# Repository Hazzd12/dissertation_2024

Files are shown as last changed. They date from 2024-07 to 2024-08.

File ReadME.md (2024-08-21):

### README.md for Lumiverse Strip

#### Project Overview

The "Lumiverse Strip" is an advanced smart lighting system that utilizes WS2812B LED strips to create a dynamic and responsive environment within smart homes. This system integrates various functionalities such as voice control, music ambience lighting, environmental monitoring, motion detection, gesture and app-controlled text display, weather simulation, and circadian rhythm lighting. The purpose of this project is to demonstrate how smart lighting can enhance user interaction, adapt to environmental changes, and improve the overall quality of life in residential spaces.

#### Features

- **Voice Control**: Manage lighting settings via voice commands.
- **Music Ambience Lighting**: Sync lights with music for immersive experiences.
- **Environmental Monitoring**: Sensors that report real-time data such as temperature, humidity, and air quality.
- **Motion Detection**: Automated lighting adjustments based on detected movement.
- **Gesture and App-Controlled Text Display**: Display messages or alerts through gesture recognition or mobile app interactions.
- **Weather Simulation**: Simulate real-time weather conditions through lighting effects.
- **Circadian Rhythm Lighting**: Adjust lighting to align with natural circadian rhythms to support better sleep patterns and general well-being.

#### Modes

**Moving Mode**

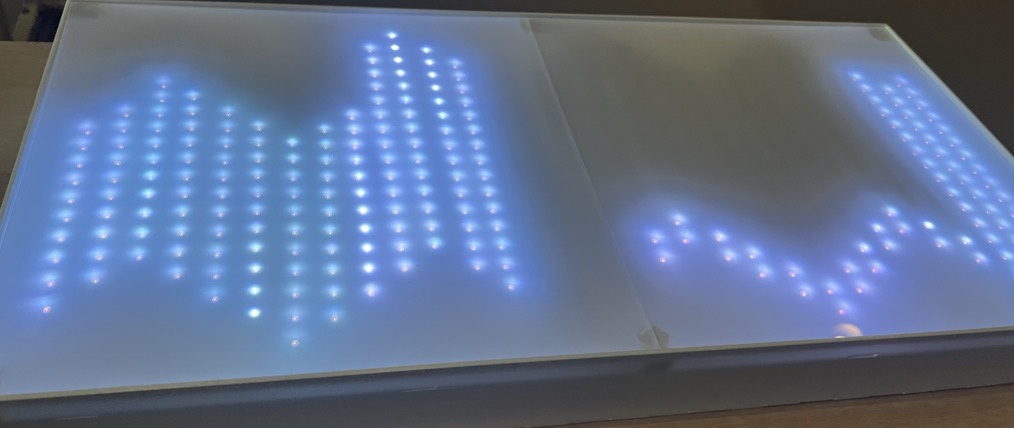
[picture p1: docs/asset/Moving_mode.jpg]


**Music Mode**

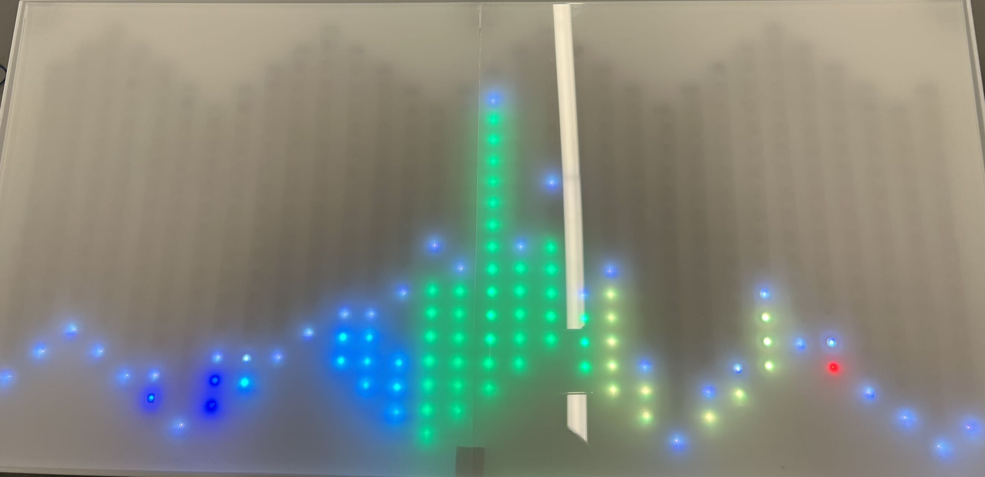
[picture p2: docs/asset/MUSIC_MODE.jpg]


**Environment Mode**

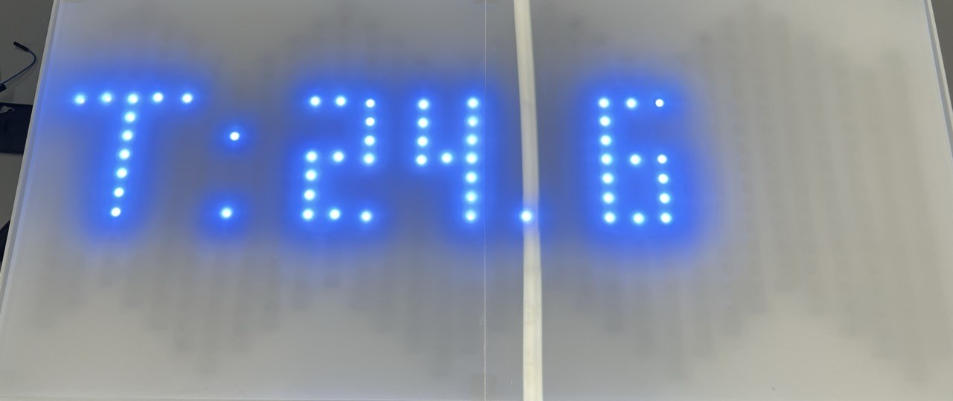
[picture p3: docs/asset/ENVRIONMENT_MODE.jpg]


**Life Mode**

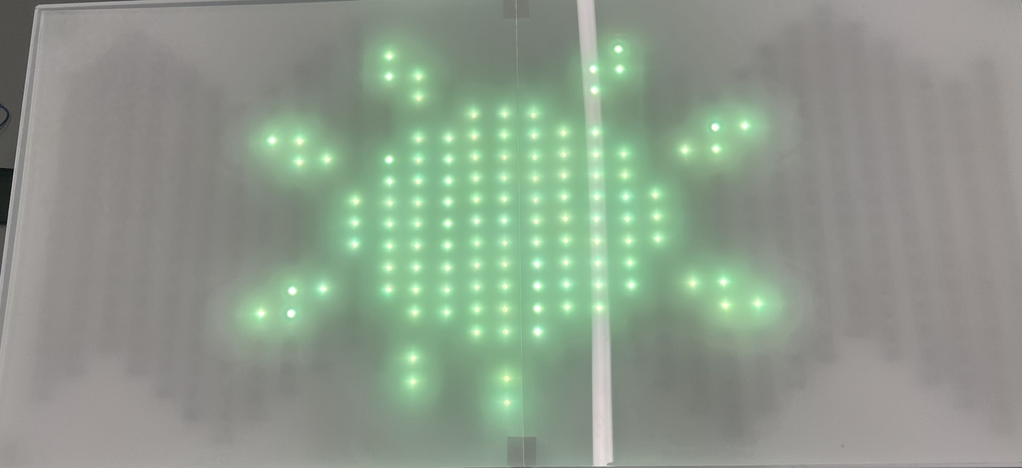
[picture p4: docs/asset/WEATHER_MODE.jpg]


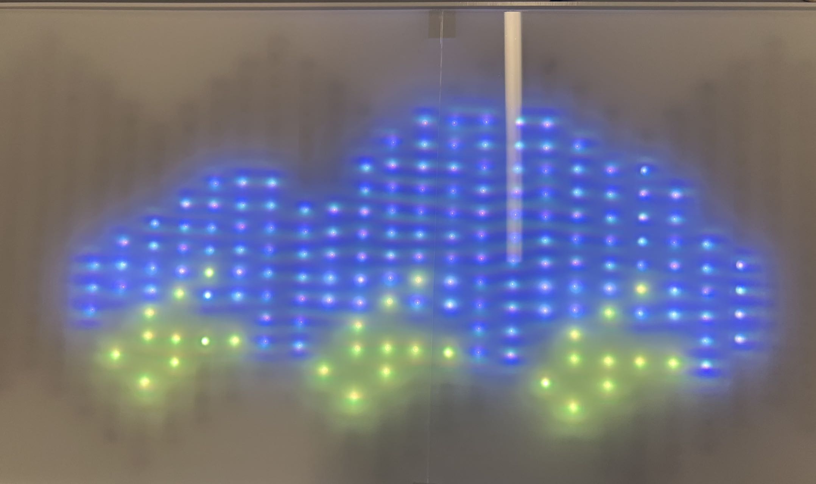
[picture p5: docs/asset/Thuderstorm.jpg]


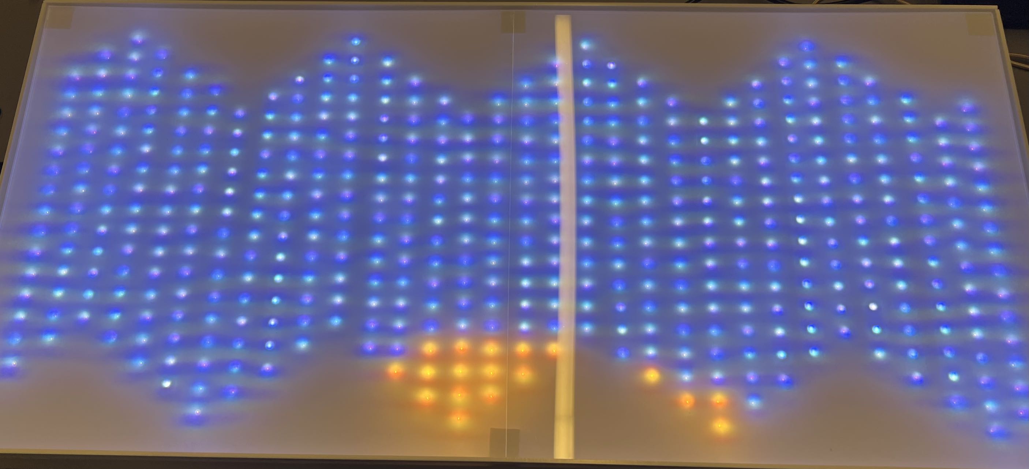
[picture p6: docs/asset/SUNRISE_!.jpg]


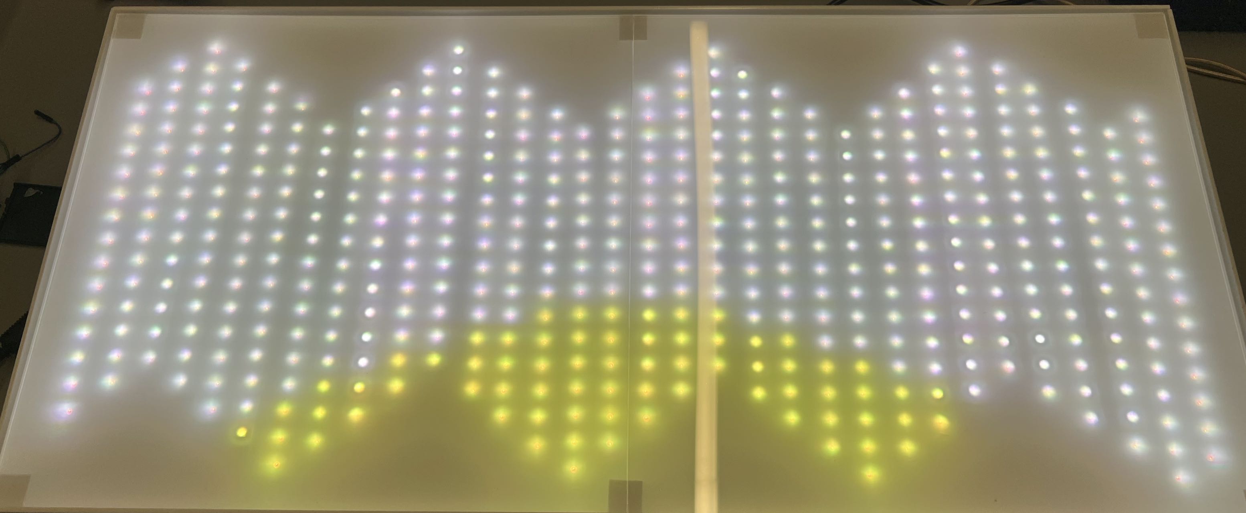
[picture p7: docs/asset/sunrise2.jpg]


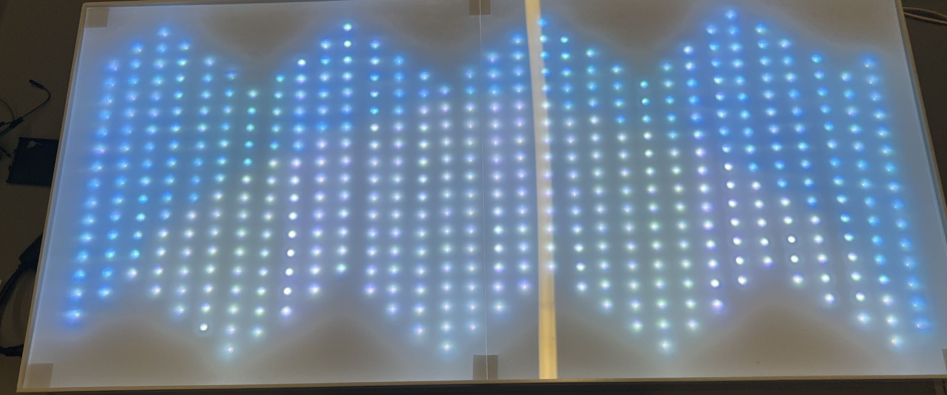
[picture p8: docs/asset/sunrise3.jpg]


****

## How to Make It

### Hardware

* WS2812B LED Strip
* ESP32 Microcontroller
* HC-SR501 PIR Motion Sensors
* MAX9814 Audio Amplifier
* DF2301QG Voice Recognition Module
* BME680 Environmental Sensor
* APDS-9960 Gesture Recognition Sensor
* Power Supply (5V 15A recommended)
* Acrylic sheets (for enclosures)
* Wires, resistors, and other standard electronics components

####  Cut the Enclosures 

* Use a laser cutter to cut 3mm acrylic sheets according to the stored file (path: `./dxf/file_name.dxf`). The names of files represent which part they are belong to.
  * Sensor Box:
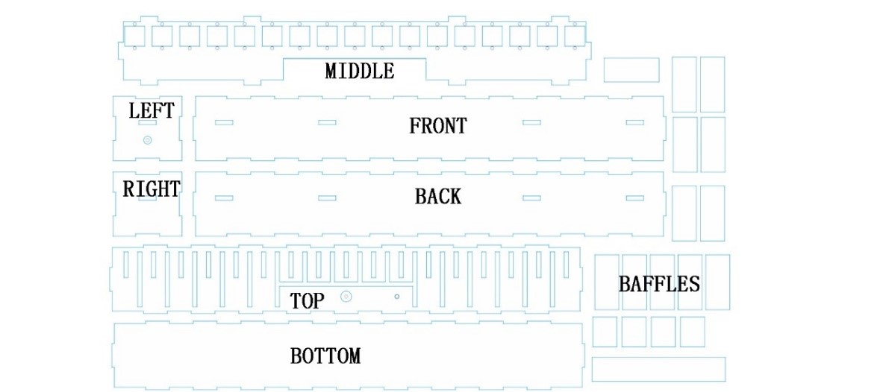
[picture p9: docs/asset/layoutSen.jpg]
    * 
  * Led Box:
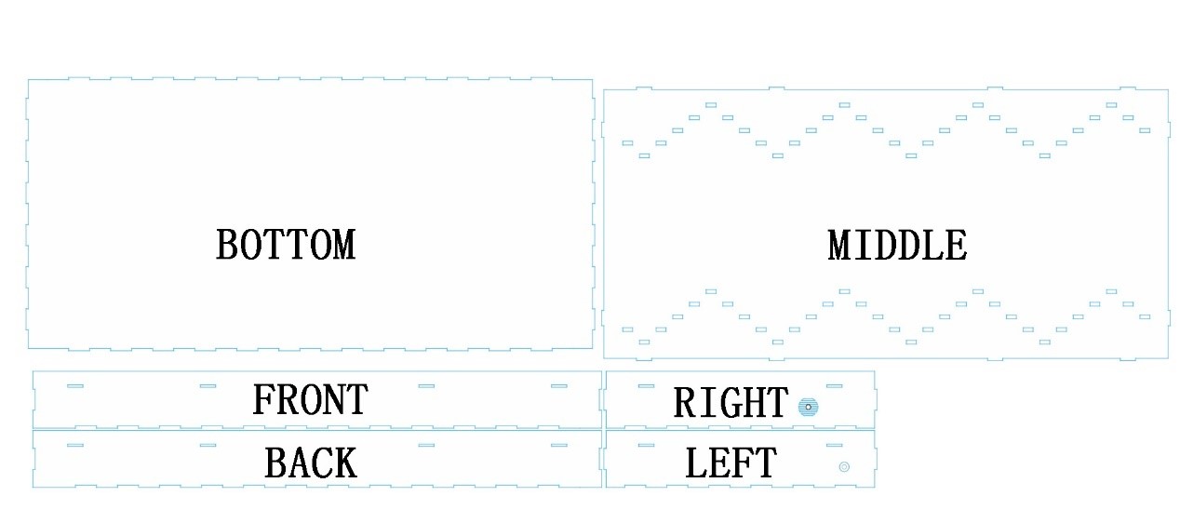
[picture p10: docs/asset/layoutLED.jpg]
    * 

### Assemble the Hardware

1. **Sensor Box Assembly:**

   * Assemble the circuit according to the circuit diagram
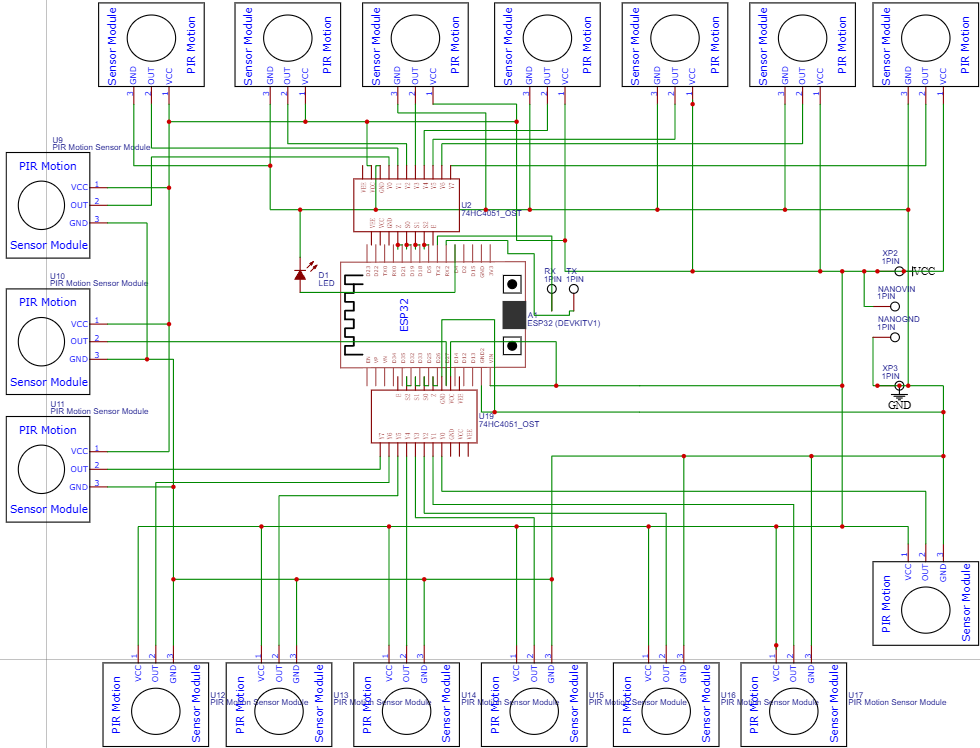
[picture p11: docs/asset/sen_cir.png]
     * 
     * Arrange the WS2812B LED strips in a wavy pattern, aligning with the height differences between the columns.
     * Route the wires (VCC, GND, and data) through the holes in the "MIDDLE" panel and secure them between the "MIDDLE" and "BOTTOM" layers.

   - Insert the PIR sensors into the designated holes in the "MIDDLE" panel.
   - Place the APDS-9960 sensor and the BME680 sensor into their respective slots.
   - Assemble the panels according to the labels, ensuring the correct orientation of each component.

2. **LED Box Assembly:**

   * Assemble the circuit according to the circuit diagram

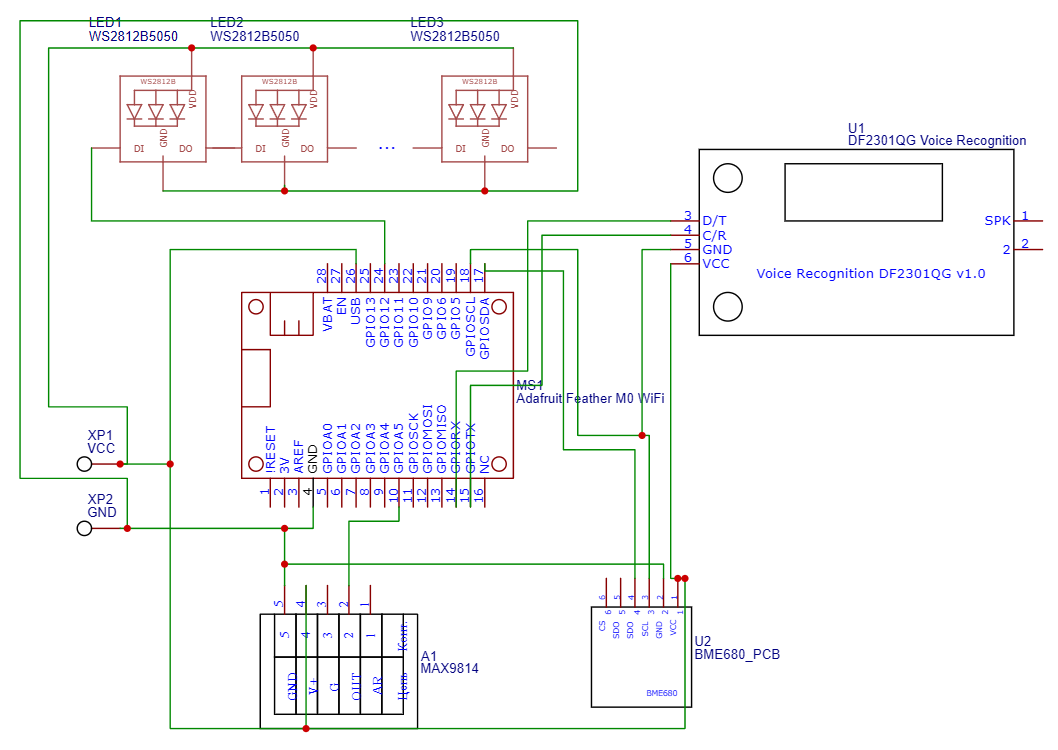
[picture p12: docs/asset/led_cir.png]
     * 

     * Connect the WS2812B LED strips to the microcontroller (Adafruit Feather M0) and ensure the power supply is sufficient to drive the entire strip.

       Connect the BME680 and DF2301QG modules to the microcontroller using I2C and UART, respectively.

   - Arrange the WS2812B LED strips in a wavy pattern, aligning with the height differences between the columns.
   - Route the wires (VCC, GND, and data) through the holes in the "MIDDLE" panel and secure them between the "MIDDLE" and "BOTTOM" layers.
   - Attach the "TOP" panel made of semi-transparent acrylic.

****

 ## Program the Microcontrollers 

**1. Setup Development Environment:**

- Install the necessary libraries for ESP32 and Adafruit Feather M0 on your development environment (e.g., Arduino IDE).
- Clone the repository and upload the provided code(path: `./Arduino/...`) to the respective microcontrollers.
  - `led` folder is provided to Adafruit Feather M0 WiFi (LED Box)
  - `Moving` folder is provided to ESP32 (Sensor Box)
  - `nano` folder is provided to Arduino nano 33 BLE (if you don't have a single APDS-9600, you can use this one)

**2. Configure MQTT:**

- Set up an MQTT broker (e.g., Mosquitto) and configure the microcontrollers to communicate via MQTT for sensor data transmission and LED control.

**3. Test Functionality:**

- Power on the system and verify that each function (e.g., motion detection, voice control, music synchronization) operates as expected.
- Troubleshoot any issues, such as incorrect sensor readings or LED behavior.

****

### Deploy and Enjoy

1. **Deploy the System:**
   - Place the Sensor Box and LED Box in their designated locations within your smart home environment.
   - Ensure they are connected to your home network and the MQTT broker is running smoothly.
2. **Customize and Expand:**
   - Customize the settings via the provided app or adjust the code to better suit your environment.
   - Consider expanding the system with additional sensors or integrating it with other smart home devices.

****

## Flowchart

Here are some flowcharts of the design of the code:

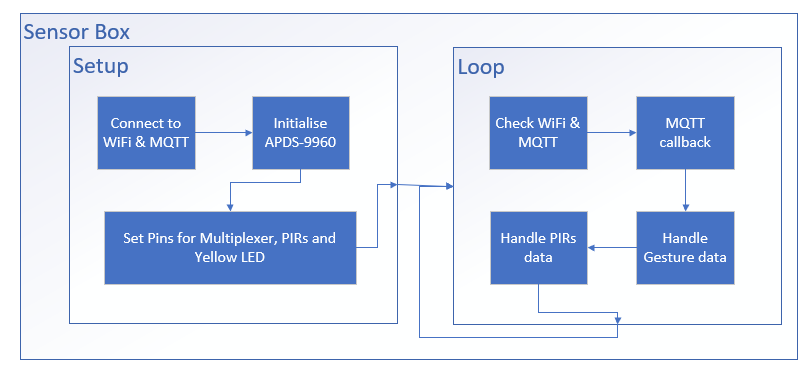
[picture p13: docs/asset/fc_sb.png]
* 
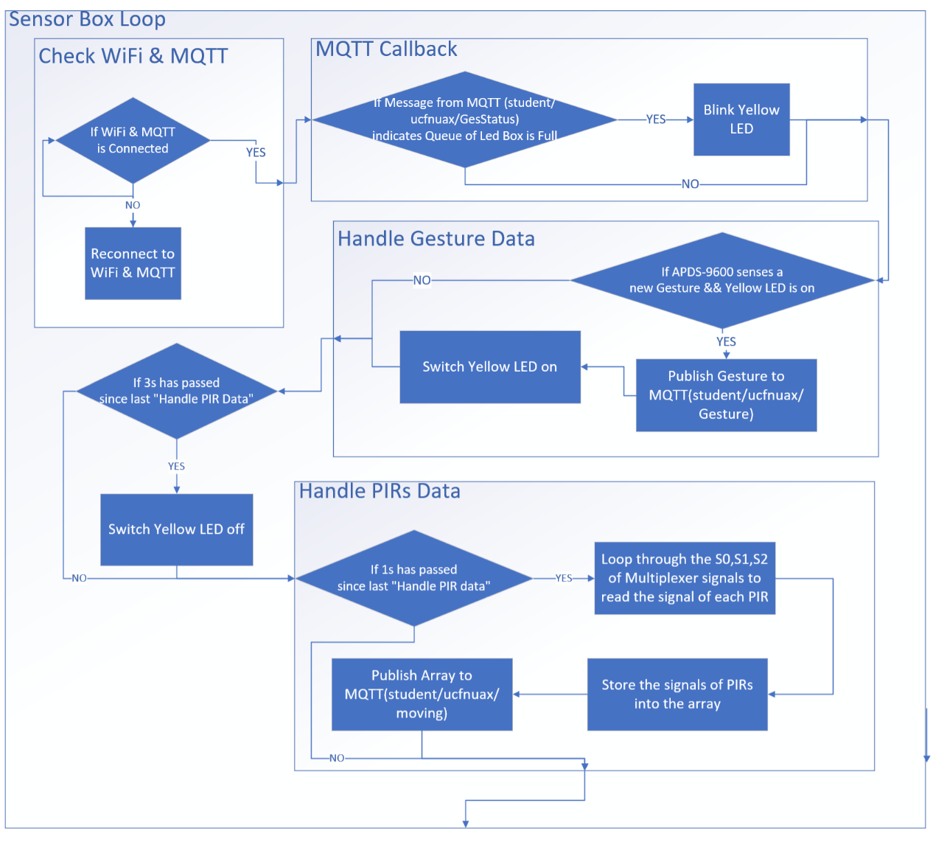
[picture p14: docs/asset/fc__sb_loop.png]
* 
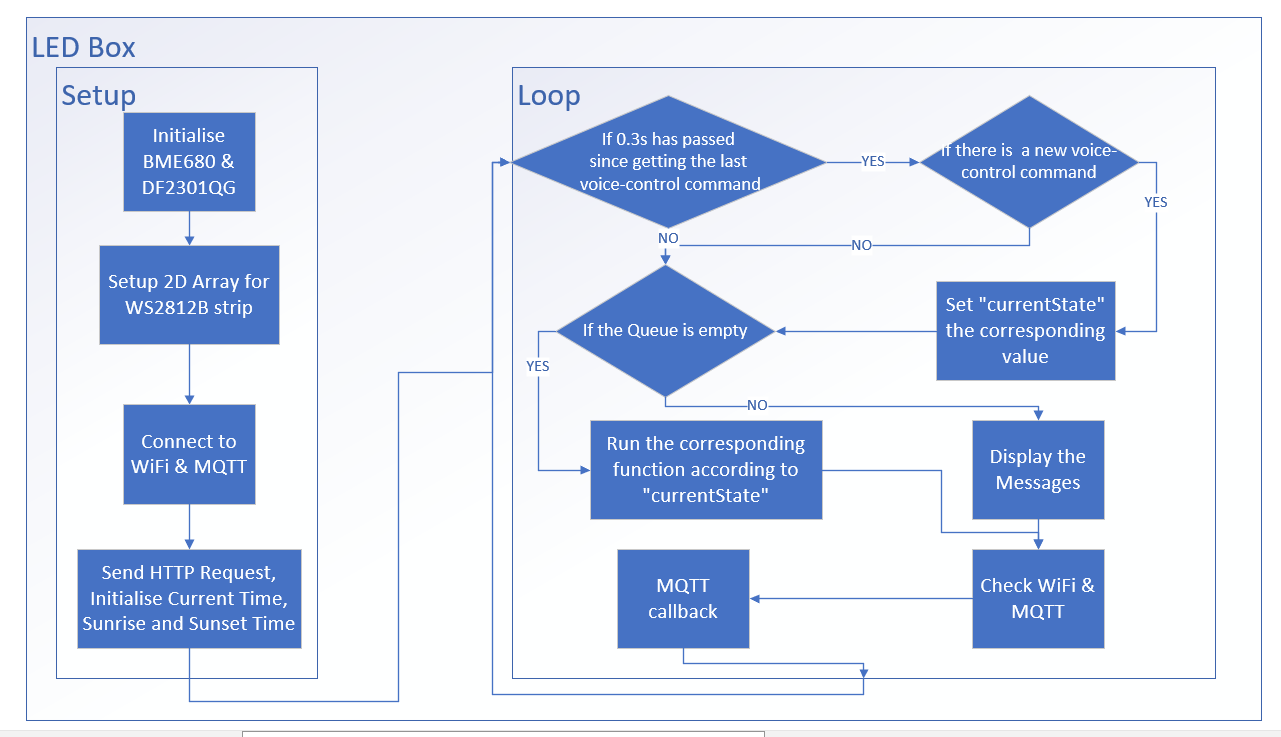
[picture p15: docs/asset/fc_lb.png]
* 
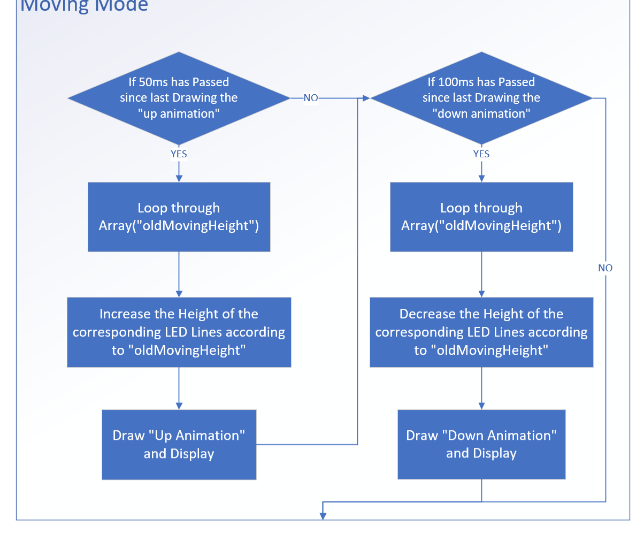
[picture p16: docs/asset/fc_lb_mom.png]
* 
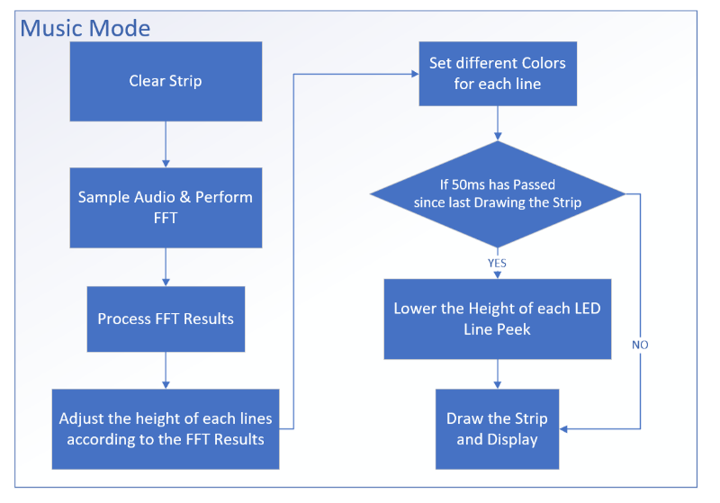
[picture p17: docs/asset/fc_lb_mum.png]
* 
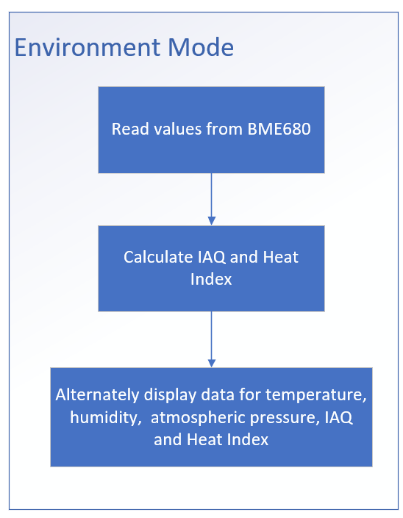
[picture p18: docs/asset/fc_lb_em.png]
* 
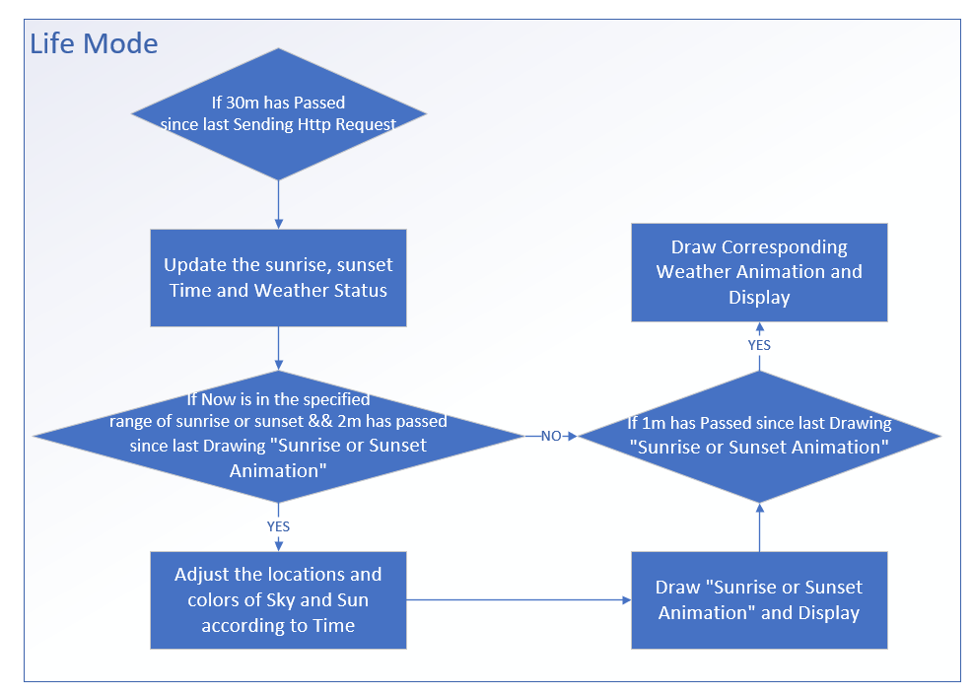
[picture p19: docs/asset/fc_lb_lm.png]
* 

****

## APP

Download apk [here](https://github.com/Hazzd12/dissertation_2024/releases/tag/v1.2.43)

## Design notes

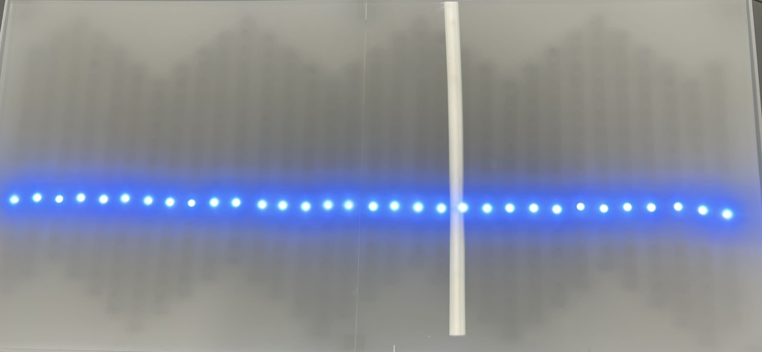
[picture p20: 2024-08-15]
docs/asset/WAKE_MODE.jpg

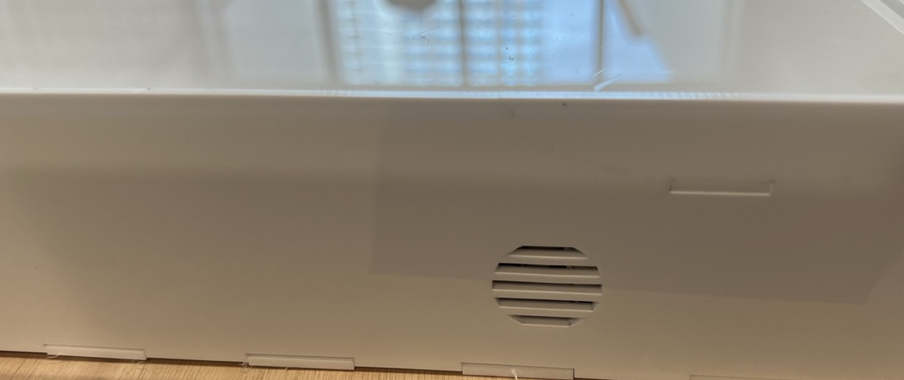
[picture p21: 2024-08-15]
docs/asset/HOLE.jpg

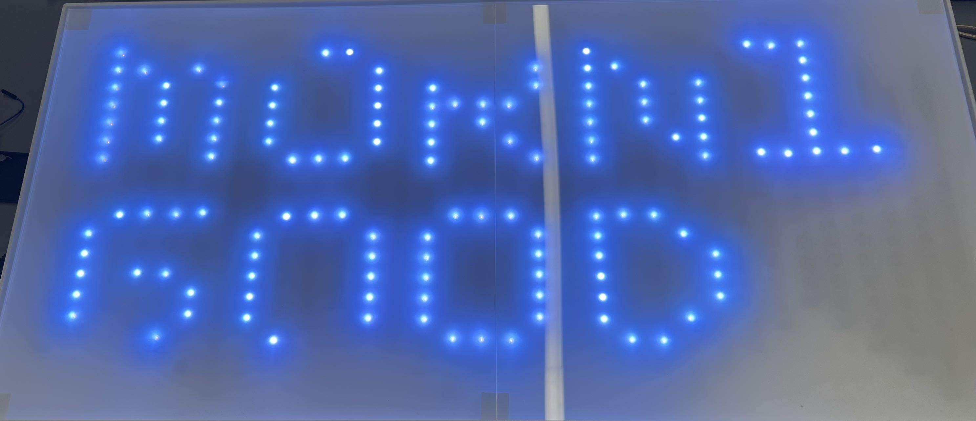
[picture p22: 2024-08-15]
docs/asset/TEXT.jpg

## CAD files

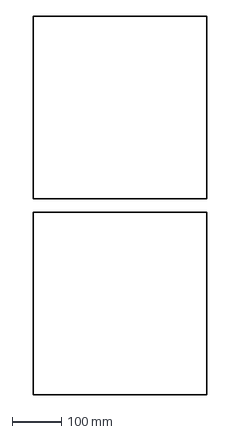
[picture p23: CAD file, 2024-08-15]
dxf/sensor_box_lid.dxf
354.0 x 772.0 mm

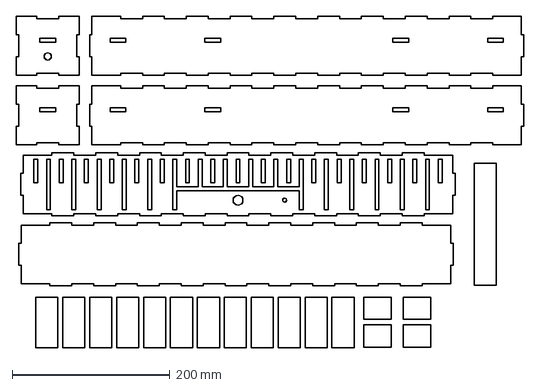
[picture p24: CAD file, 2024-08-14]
dxf/SENSOR_BOX_8.7NEW.dxf
643.0 x 420.0 mm

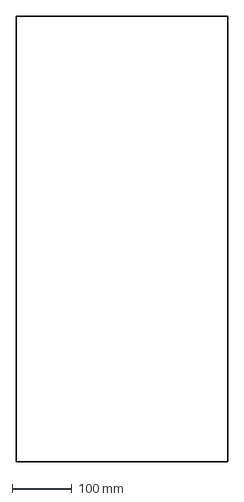
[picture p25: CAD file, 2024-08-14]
dxf/led_box_lid.dxf
354.0 x 744.0 mm

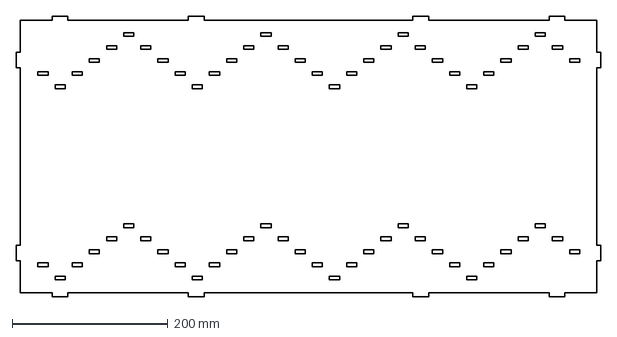
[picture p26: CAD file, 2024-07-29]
dxf/led_middle_5mm.dxf
750.0 x 360.0 mm

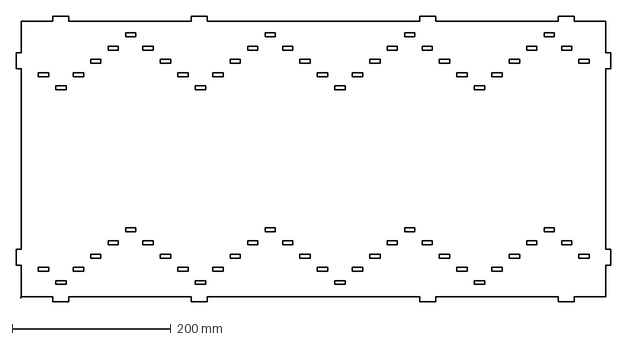
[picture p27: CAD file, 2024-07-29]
dxf/led_middle_6mm.dxf
750.0 x 360.0 mm

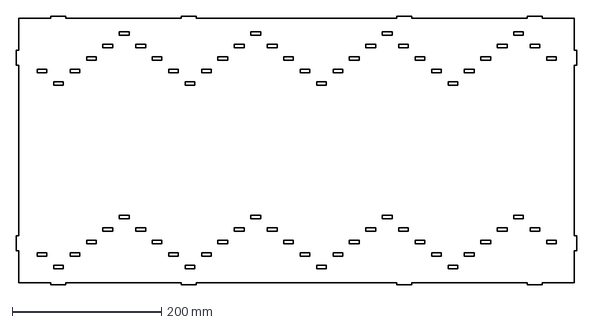
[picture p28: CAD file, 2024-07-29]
dxf/led_middle_3mm.dxf
750.0 x 360.0 mm

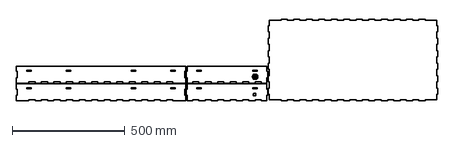
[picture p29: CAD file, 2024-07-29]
dxf/led_box_5mm.dxf
1866.0 x 360.0 mm

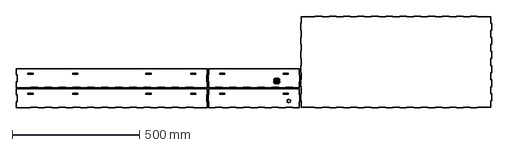
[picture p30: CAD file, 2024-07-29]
dxf/led_box_3mm.dxf
1866.0 x 360.0 mm

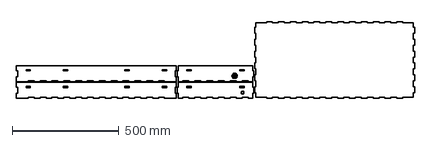
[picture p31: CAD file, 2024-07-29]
dxf/led_box_6mm(new).dxf
1866.0 x 360.0 mm

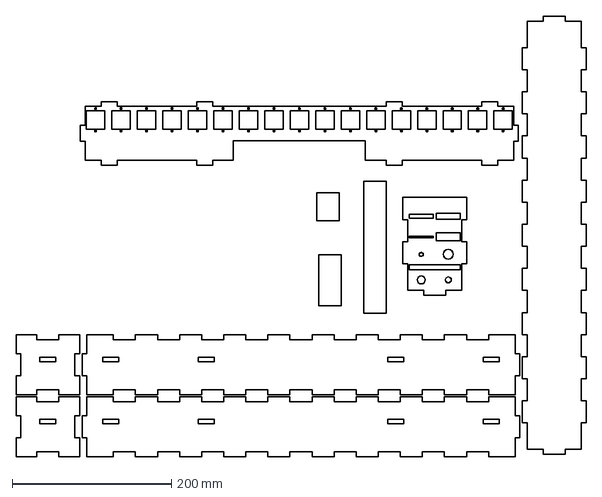
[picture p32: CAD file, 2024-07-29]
dxf/sensor_box_v2.dxf
716.0 x 553.0 mm

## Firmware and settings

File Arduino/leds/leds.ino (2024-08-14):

#include <cppQueue.h>
#include <ArduinoJson.h>
#include "strip.h"
#include "myWifi.h"
#include "MQTTClient.h"
#include "myMusic.h"
#include "LifeAndEnvrionment.h"
#include <Wire.h>
#include <SPI.h>
#include <Adafruit_Sensor.h>
#include "Adafruit_BME680.h"
#include "common.h"
#include "DFRobot_DF2301Q.h"

#define Led 9

DFRobot_DF2301Q_UART* asr;


#define SEALEVELPRESSURE_HPA (1013.25)

Adafruit_BME680 bme;  // I2C

enum State {
  TEST_MODE,
  MOVING_MODE,
  MUSIC_MODE,
  ENVIRONMENT_MODE,
  LIFE_MODE,
  WAKE_MODE
};

State currentState = MOVING_MODE;
State lastState = MOVING_MODE;
int movingArray[17] = { 0 };
int oldMovingHeight[32] = { 0 };

cppQueue myQueue(sizeof(Mes*), 11, FIFO, true);
unsigned long previousMillis = 0;
const long interval = 2000;  // 2 seconds
String segments[10];
int spaces[10];

float temperature = 0;
float humidity = 0;
float pressure = 0;
float gas = 0;
float IAQ = 0;
float heatIndex = 0;

unsigned long lastStringTime = 0;
unsigned long VoiceTime = 0;
unsigned long EnvTime = 0;
int envIndex = 0;
int envDuration = 5000;

int lastTimeCheck = 0;
int lastUpdateTime = 0;
bool ifRiseSet = false;
bool ifWake = false;
bool ifCancelWake = false;

unsigned long lastWake = 0;
void setup() {
  // 初始化灯带
  Serial.begin(9600);
  Serial.println("start");
  delay(1000);

  //BME setup
  Serial.println(F("BME680 test"));

  // Initialize the sensor
  if (!bme.begin()) {
    Serial.println(F("Could not find a valid BME680 sensor, check wiring!"));
  }

  // Set up oversampling and filter initialization
  bme.setTemperatureOversampling(BME680_OS_8X);
  bme.setHumidityOversampling(BME680_OS_2X);
  bme.setPressureOversampling(BME680_OS_4X);
  bme.setIIRFilterSize(BME680_FILTER_SIZE_3);
  bme.setGasHeater(320, 150);  // 320*C for 150 ms

  delay(2000);

  //strip setup
  setupStrip();

  //matrix setup
  ledSetup();
  // initMatrix();
  strip.begin();

  char st1[] = "AUDIO";
  drawString(st1, strip.Color(255, 255, 255), 1, 7);
  strip.show();  // 初始化所有像素为'关'

  asr = new DFRobot_DF2301Q_UART(&Serial1);

  // Init the sensor
  while (!(asr->begin())) {
    Serial.println("Communication with device failed, please check connection");
    delay(3000);
  }
  Serial.println("Begin ok!");

  asr->settingCMD(DF2301Q_UART_MSG_CMD_SET_MUTE, 1);
  asr->settingCMD(DF2301Q_UART_MSG_CMD_SET_VOLUME, 7);
  asr->settingCMD(DF2301Q_UART_MSG_CMD_SET_WAKE_TIME, 10);
  //asr->settingCMD(DF2301Q_UART_MSG_CMD_SET_ENTERWAKEUP, 0);

  asr->playByCMDID(23);
  Serial.println("IN");
  strip.clear();

  char st2[] = "SETUP";
  drawString(st2, strip.Color(255, 255, 255), 1, 7);
  strip.show();  // 初始化所有像素为'关'
  WiFiAndMQTTConnection(callback);


  httpclient.setTimeout(5000);
  // Setup MQTT subscription
  sendGetRequest();
  strip.clear();


  randomSeed(analogRead(2));
}



void loop() {
  MQTTloop();

  unsigned long nowT = millis();
  if (nowT - VoiceTime >= 300) {
    VoiceTime = nowT;
    uint8_t CMDID = asr->getCMDID();

    if (CMDID != 0) {
      Serial.print("CMDID = ");  //打印命令ID
      Serial.println(CMDID);
    }

    switch (CMDID) {
      case 5:  //music

        currentState = MUSIC_MODE;
        break;

      case 6:  //moving
        currentState = MOVING_MODE;
        break;

      case 7:  //life - indoor
        currentState = LIFE_MODE;
        break;

      case 8:  //environment - outdoor
        currentState = ENVIRONMENT_MODE;
        break;

      case 117:
        currentState = TEST_MODE;
        break;
      case 1:
        lastState = currentState;
        currentState = WAKE_MODE;
        ifWake = true;
        lastWake = nowT;
        break;
      default:
        break;
    }
  }

  int queueCount = myQueue.getCount();
  if (queueCount > 0) {
    if (nowT - lastStringTime > 700) {
      drawStrings();
      lastStringTime = nowT;
    }
  } else {
    switch (currentState) {
      case WAKE_MODE:
        if (ifWake) {
          ifWake = false;
          drawHorizontalLine(7);
        }

        if (nowT - lastWake > 5000 ) {
          currentState = lastState;
          strip.clear();
          strip.show();
          Serial.println("12356");
        }
        break;
      case MUSIC_MODE:
        // 在这里持续执行功能A

        drawRHYTHM();
        delay(5);
        break;

      case MOVING_MODE:
        // 在这里持续执行功能B
        drawMoving(movingArray, oldMovingHeight);
        delay(5);
        break;

      case LIFE_MODE:
        Lifeloop(nowT);
        break;

      case ENVIRONMENT_MODE:

        if (nowT - EnvTime >= envDuration) {
          Serial.println("Executing ENVIRONMENT_MODE...");
          Envrionmentloop();
          drawEnvironment();
          envIndex = (++envIndex) % 10;
          Serial.print("envIndex");
          Serial.println(envIndex);
          EnvTime = nowT;
        }
        break;

      case TEST_MODE:
        test_loop();

        break;

      default:
        break;
    }
  }
}

void test_loop() {
  strip.clear();
  drawRSun(0, -15);
  strip.show();
  delay(5000);
  for (int j = -14; j <= 0; j++) {
    strip.clear();
    drawRSun((int)(3 - j / (-5)), j);
    delay(1000);
    strip.show();
  }
  for (int x = 0; x < 5; x++) {
    for (int i = 0; i < 10; i++) {
      drawWeather(x, millis());
      delay(1000);
    }
  }
  currentState = MUSIC_MODE;
}

void callback(char* topic, byte* payload, unsigned int length) {
  // 处理接收到的消息
  Serial.print("Message arrived [");
  Serial.print(topic);
  Serial.print("] ");
  Serial.println(length);

  for (int i = 0; i < length; i++) {
    Serial.print((char)payload[i]);
  }
  Serial.println();

  if (strcmp(topic, "student/ucfnuax/moving") == 0) {
    handlePeopleMoving(payload, length);
  }
  if (strcmp(topic, "student/ucfnuax/Gesture") == 0) {
    String message;
    message = handleGesture((char)payload[0]);
    handleString(message);
  }

  if (strcmp(topic, "student/ucfnuax/Message") == 0) {
    String message;
    for (int i = 0; i < length; i++) {
      message += (char)payload[i];
    }
    handleString(message);
    Serial.println(myQueue.getCount());
  }
}

void handlePeopleMoving(byte* payload, int length) {
  // 解析JSON消息
  DynamicJsonDocument doc(1024);
  DeserializationError error = deserializeJson(doc, payload, length);

  if (error) {
    Serial.print("Failed to parse JSON: ");
    Serial.println(error.c_str());
    return;
  }

  JsonArray jsonArray = doc.as<JsonArray>();
  Serial.print("Received array: ");
  int i = 0;
  for (JsonVariant v : jsonArray) {
    Serial.print(v.as<int>());
    Serial.print(" ");
    movingArray[i] = v.as<int>();
    i++;
    if (i > 16) break;
  }
  Serial.println();
  for (int isa : movingArray) {
    Serial.print(isa);
    Serial.print(" ");
  }
  Serial.println();
  handleMoving(movingArray, oldMovingHeight);
}

String handleGesture(char message) {
  if (message == 'u')
    return "GOOD MORNING";
  else if (message == 'd')
    return "GOOD AFTERNOON";
  else if (message == 'l')
    return "HELLO";
  else if (message == 'r')
    return "GOOD EVENING";
  else
    return "";
}

void handleString(String message) {

  int count = splitString(message);

  if (count + myQueue.getCount() > 10) {
    client.publish("student/ucfnuax/GesStatus", "0");
  } else {
    client.publish("student/ucfnuax/GesStatus", "1");
    for (int i = 0; i < count; i++) {
      String met = segments[i];


      Mes* temp = new Mes();
      const char* c_mes = met.c_str();
      strcpy(temp->message, c_mes);

      int queueCount = myQueue.getCount();

      temp->yLocation = queueCount * 8 + 19 - spaces[i];
      myQueue.push(&temp);
    }
  }
}

void drawStrings() {
  strip.clear();
  int count = myQueue.getCount();
  for (int i = 0; i < count; i++) {

    Mes* temp;
    myQueue.pop(&temp);

    drawString(temp->message, strip.Color(255, 255, 255), 1, temp->yLocation);
    Mes* temp2 = new Mes();
    temp2->yLocation = temp->yLocation - 1;
    strcpy(temp2->message, temp->message);

    if (temp2->yLocation > -7) {
      myQueue.push(&temp2);
    } else {
      delete temp2;
    }
    delete temp;
  }

  strip.show();
}


//test function, test which led may be broken or disconnected
void colorWipe(uint32_t color, int wait) {
  for (int i = 0; i < 32; i++) {
    drawLine(i, color);
  }
  delay(wait);
  strip.show();
}


int splitString(String str) {
  String segment = "";
  int count = 0;
  for (int i = 0; i < str.length(); i++) {
    char c = str.charAt(i);
    if (c == ' ') {
      if (segment.length() > 0) {
        spaces[count] = 1;
        segments[count++] = segment;
        segment = "";
      }
    } else {
      segment += c;
      if (segment.length() == 5) {
        spaces[count] = 0;
        segments[count++] = segment;
        segment = "";
      }
    }
  }
  if (segment.length() > 0) {
    spaces[count] = 0;
    segments[count++] = segment;
  }
  return count;
}

void drawEnvironment() {
  String info;
  strip.clear();
  switch (envIndex) {
    case 0:
      info = "TEMPE";
      envDuration = 2000;
      break;
    case 1:
      info = "T:" + String(temperature, 1);
      envDuration = 30000;
      break;
    case 2:
      info = "HUMID";
      envDuration = 2000;
      break;
    case 3:
      info = "H:" + String(humidity, 1);
      envDuration = 3000;
      break;
    case 4:
      info = "PRESS";
      envDuration = 2000;
      break;
    case 5:
      info = "P:" + String(pressure, 2);
      envDuration = 3000;
      break;
    case 6:
      info = "IAQ:" + String((int)IAQ);
      envDuration = 5000;
      break;
    case 7:
      info = "HEAT";
      envDuration = 1000;
      break;
    case 8:
      info = "INDEX";
      envDuration = 1000;
      break;
    case 9:
      info = "HI:" + String(heatIndex, 1);
      envDuration = 1000;
      break;
    default:
      break;
  }
  const char* charArray = info.c_str();
  char* mes = const_cast<char*>(charArray);
  drawString(mes, strip.Color(255, 255, 255), 0, 7);
  strip.show();
}


void Lifeloop(unsigned long nowT) {

  if (nowT - lastUpdateTime > 30 * 60 * 1000) {
    sendGetRequest();
    lastUpdateTime = nowT;
  }


  if (nowT - lastTimeCheck > 2 * 60 * 1000) {
    time_t currentTime = now();
    int minutesLeft = (currentTime - sunrise) / 60;  // 计算到日出的分钟数

    if (minutesLeft < 30 && minutesLeft >= -5) {  // 如果距离日出30分钟或更少
      int index = (int)(minutesLeft / 10) + 1;
      if (index < 0) index = 0;
      int y = (int)(minutesLeft / 2) - 15;
      if (y > 0) y = 0;
      drawRSun(index, y);  // 调用特定的函数
      ifRiseSet = true;
    }

    minutesLeft = (sunset - currentTime) / 60;  // 计算到日出的分钟数

    Serial.print("Minutes to sunset: ");
    Serial.println(minutesLeft);

    if (minutesLeft < 30 && minutesLeft >= -5) {  // 如果距离日出30分钟或更少
      int index = (int)(minutesLeft / 10) + 1;
      if (index < 0) index = 0;
      int y = (int)(minutesLeft / 2) - 15;
      if (y > 0) y = 0;
      drawRSun(index, y);  // 调用特定的函数
      ifRiseSet = true;
    }
    lastTimeCheck = nowT;
  }

  if (ifRiseSet && nowT - lastTimeCheck > 60 * 1000) {
    ifRiseSet = false;
  }

  if (!ifRiseSet) {
    drawWeather(currentWea, nowT);
  }
}

void Envrionmentloop() {

  if (!bme.performReading()) {
    Serial.println(F("Failed to perform reading :("));
    delay(1000);
    return;
  }

  temperature = bme.temperature;
  humidity = bme.humidity;
  pressure = bme.pressure / 100.0;
  gas = bme.gas_resistance / 1000.0;



  Serial.print(F("Temperature = "));
  Serial.print(temperature);
  Serial.println(F(" *C"));

  Serial.print(F("Pressure = "));
  Serial.print(pressure);
  Serial.println(F(" hPa"));

  Serial.print(F("Humidity = "));
  Serial.print(humidity);
  Serial.println(F(" %"));

  Serial.print(F("Gas = "));
  Serial.print(gas);
  Serial.println(F(" KOhms"));


  // Calculate Air Quality Index (simple estimation based on gas resistance)
  IAQ = calculateIAQ(temperature, humidity, gas);
  Serial.print(F("Estimated IAQ = "));
  Serial.println(IAQ);

  // Calculate Heat Index
  heatIndex = calculateHeatIndex(temperature, humidity);
  Serial.print(F("Heat Index = "));
  Serial.print(heatIndex);
  Serial.println(F(" *C"));


  Serial.println();
}


float calculateIAQ(float temperature, float humidity, float gas) {
  // Simplified IAQ calculation for demonstration purposes
  // Temperature and humidity can affect gas sensor readings
  float gas_baseline = 500.0;  // Baseline value for gas resistance in KOhms

  // Calculate a humidity score
  float humidity_score;
  if (humidity >= 30 && humidity <= 60) {
    humidity_score = 0.25 * 100;
  } else {
    if (humidity < 30) {
      humidity_score = 0.25 * (humidity / 30.0) * 100;
    } else {
      humidity_score = 0.25 * ((100 - humidity) / 40.0) * 100;
    }
  }

  // Calculate a gas score
  float gas_score;
  if (gas > gas_baseline) {
    gas_score = 0.75 * (gas_baseline / gas) * 100;
  } else {
    gas_score = 0.75 * 100;
  }

  // Calculate air quality index (IAQ)
  float IAQ = humidity_score + gas_score;
  return IAQ;
}

float calculateHeatIndex(float temperature, float humidity) {
  // Calculate heat index using the formula from NOAA
  float T = temperature;
  float R = humidity;
  float HI = 0.5 * (T + 61.0 + ((T - 68.0) * 1.2) + (R * 0.094));

  if (HI >= 80) {
    HI = -42.379 + 2.04901523 * T + 10.14333127 * R
         - 0.22475541 * T * R - 6.83783e-3 * T * T
         - 5.481717e-2 * R * R + 1.22874e-3 * T * T * R
         + 8.5282e-4 * T * R * R - 1.99e-6 * T * T * R * R;
  }
  return HI;
}

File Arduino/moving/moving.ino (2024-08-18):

#define S10 25
#define S11 33  // 修改为有效的引脚号
#define S12 32
#define Z1 26  // 将Z设置为数字引脚，而不是模拟引脚
#define PIR8 27
#define S20 19
#define S21 18
#define S22 5
#define Z2 21

#define LED 4
#include <WiFi.h>  // 使用ESP32的WiFi库
#include <PubSubClient.h>
#include <ArduinoJson.h>
#include "myWifi.h"

const char* ssid = SSID;
const char* password = PASSWORD;

// MQTT broker address and port
const char* mqtt_server = MQTT_SERVER;
const int mqtt_port = MQTT_PORT;
const char* mqtt_user = MQTT_USER;
const char* mqtt_pass = MQTT_PASS;


const char* publish_topic = "student/ucfnuax/moving";

const char* subscribe_topics[] = { "student/ucfnuax/status",
                                   "student/ucfnuax/GesStatus" };

unsigned long lastPublish = 0;
unsigned long lastLed = 0;
/// Create WiFi and MQTT client objects
WiFiClient espClient;
PubSubClient client(espClient);

bool status = true;
bool ledSt = false;

int PIRs[17];

void setup() {
  Serial2.begin(115200, SERIAL_8N1, 16, 17);  // RX2默认为16, TX2默认为17

  Serial.begin(9600);  // 用于调试的串口

  setup_wifi();


  client.setServer(mqtt_server, mqtt_port);
  client.setCallback(callback);
  String macAddress = WiFi.macAddress();
  // 输出MAC地址
  Serial.println("MAC Address: " + macAddress);
  set_PIRs();
  pinMode(LED, OUTPUT);
  digitalWrite(LED, HIGH);
}

void loop() {

  unsigned long nowTime = millis();

  if (!client.connected()) {
    mqtt_connect_and_subscribe();
  }

  if (Serial2.available() && !ledSt) {
    digitalWrite(LED, HIGH);
    ledSt = true;
    lastLed = nowTime;
    String received = Serial2.readString();
    mqtt_publish_Ges(received);
    Serial.println("Received from Nano 33 BLE: " + received);  // 输出到PC
  }

  if (ledSt && nowTime - lastLed > 3000) {
    ledSt = false;
    String received = Serial2.readString();
    digitalWrite(LED, LOW);

  }

  client.loop();




  // 每隔1秒发布一次数组
  if (nowTime - lastPublish > 1000 && status) {
    loop_PIRs();
    lastPublish =nowTime;
    mqtt_publish_PIR(PIRs, 17);
  }
}

void setup_wifi() {
  delay(10);
  Serial.println();
  Serial.print("Connecting to ");
  Serial.println(ssid);

  WiFi.begin(ssid, password);

  while (WiFi.status() != WL_CONNECTED) {
    delay(500);
    Serial.print(".");
  }

  Serial.println("");
  Serial.println("WiFi connected");
  Serial.println("IP address: ");
  Serial.println(WiFi.localIP());
}


void set_PIRs() {
  pinMode(S10, OUTPUT);
  pinMode(S11, OUTPUT);
  pinMode(S12, OUTPUT);
  Serial.begin(9600);
  pinMode(Z1, INPUT_PULLDOWN);
  pinMode(S20, OUTPUT);
  pinMode(S21, OUTPUT);
  pinMode(S22, OUTPUT);
  pinMode(Z2, INPUT_PULLDOWN);
  pinMode(PIR8, INPUT);
}


void mqtt_connect_and_subscribe() {
  while (!client.connected()) {
    Serial.print("Attempting MQTT connection...");
    String clientId = "ESP32Client-";
    clientId += String(random(0xffff), HEX);
    if (client.connect(clientId.c_str(), mqtt_user, mqtt_pass)) {
      Serial.println("connected");
      // Subscribe to the topic
      for (int i = 0; i < sizeof(subscribe_topics) / sizeof(subscribe_topics); i++) {
        client.subscribe(subscribe_topics[i]);
        Serial.print("Subscribed to: ");
        Serial.println(subscribe_topics[i]);
      }
    } else {
      Serial.print("failed, rc=");
      Serial.print(client.state());
      Serial.println(" try again in 5 seconds");
      delay(5000);
    }
  }
}

void mqtt_publish_PIR(int* array, size_t length) {
  // 创建一个动态JSON文档
  DynamicJsonDocument doc(1024);

  // 将数组添加到JSON文档中
  JsonArray jsonArray = doc.to<JsonArray>();
  for (size_t i = 0; i < length; i++) {
    jsonArray.add(array[i]);
  }

  // 将JSON文档序列化为字符串
  char buffer[512];
  size_t n = serializeJson(doc, buffer);

  // 发布JSON字符串到MQTT主题
  client.publish(publish_topic, buffer, n);
  Serial.print("Published array to topic: ");
  Serial.println(publish_topic);
}

void mqtt_publish_Ges(String mes) {
  const char* c_mes = mes.c_str();
  client.publish("student/ucfnuax/Gesture", c_mes);
}

int count = 0;
void callback(char* topic, byte* payload, unsigned int length) {
  Serial.print("Message arrived [");
  Serial.print(topic);
  Serial.print("] ");

  Serial.println(count++);
  // 解析JSON消息
  String message;
  for (int i = 0; i < length; i++) {
    Serial.print((char)payload[i]);
    message += (char)payload[i];
  }
  if (strcmp(topic, "student/ucfnuax/status") == 0) {
    if (message == "0") {
      status = false;
    } else if (message == "1") {
      status = true;
    }
  } else if (strcmp(topic,  ) == 0) {
    if (message == "0") {

      for (int i = 0; i < 5; i++) {
        digitalWrite(LED, HIGH);
        delay(50);
        digitalWrite(LED, LOW);
        delay(50);
      }
    }
  }
  Serial.println();
}


void loop_PIRs() {
  for (int i = 0; i < 8; i++) {
    // 设置选择引脚的状态

    digitalWrite(S10, (i & 0x01));
    digitalWrite(S11, (i & 0x02) >> 1);
    digitalWrite(S12, (i & 0x04) >> 2);

    digitalWrite(S20, (i & 0x01));
    digitalWrite(S21, (i & 0x02) >> 1);
    digitalWrite(S22, (i & 0x04) >> 2);

    delay(5);  // 增加延迟，确保通道切换完成

    int value1 = digitalRead(Z1);  // 读取选定通道的数字值
    Serial.print("Channel ");
    Serial.print(i);
    Serial.print(": ");
    Serial.println(value1);
    PIRs[i] = value1;

    int value2 = digitalRead(Z2);  // 读取选定通道的数字值
    // Serial.print("Channel ");
    // Serial.print(i + 9);
    // Serial.print(": ");
    // Serial.println(value2);
    PIRs[i + 9] = value2;
  }

  int value = digitalRead(PIR8);
  PIRs[8] = value;
  Serial.print("PIR8: ");
  Serial.println(value);
}
